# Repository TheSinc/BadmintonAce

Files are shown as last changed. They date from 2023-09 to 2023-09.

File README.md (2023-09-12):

# BadmintonAce
This is the repository of CAD & Code for my Hackaday Prize 2023 Entry.
https://hackaday.io/project/190336-badminton-ace-shuttle-launcher

Badminton Ace is a project to create a relatively low cost multi-axis robot capable of launching badminton shuttles in user defined patterns for teaching and training. This project seeks to engage children and adults in the exciting sport of badminton to improve physical health while providing an engaging mechatronics system that demonstrates the power of STEM.

Users or trainers can connect to the launcher using wifi then select and adjust shot placement and pattern to learn or practice new badminton return techniques. This will be done directly in the browser using an interactive 3D court with controls for rotation and trajectory.

The robot can also be used as a powerful STEM educational tool throughout the build process if desired. With multiple sensors, 2 brushless and 4 servo motors, 3D printing, laser cutting, urethane molding, programing, inverse kinematics, and more, this project covers a wide range of topics for those looking to learn how it all works. It also helps to encourage excercise for it's users.

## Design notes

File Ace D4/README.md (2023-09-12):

Badminton Ace Design 4
This section contains the CAD & Code for the current design variant 4.

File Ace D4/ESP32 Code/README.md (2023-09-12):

ESP32 Software & Firmware for D4 of the launcher. The code is all working but I'm not happy with the quality of calibration. The code is also a bit of a mess but it's all here for your enjoyment!

The code is for use in the Arduino IDE which is where the ESP32 is programed.

The webpage, images, and ccs are all loaded via SPIFFS. Unfortunately, this is not compatible with Arduino 2.0 so needs to be done on an older version. 

Information on the SPIFFS tool:
https://randomnerdtutorials.com/install-esp32-filesystem-uploader-arduino-ide/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,like%20the%20ESP32%20flash%20memory.

The SPIFFS Tool:
https://github.com/me-no-dev/arduino-esp32fs-plugin/releases/

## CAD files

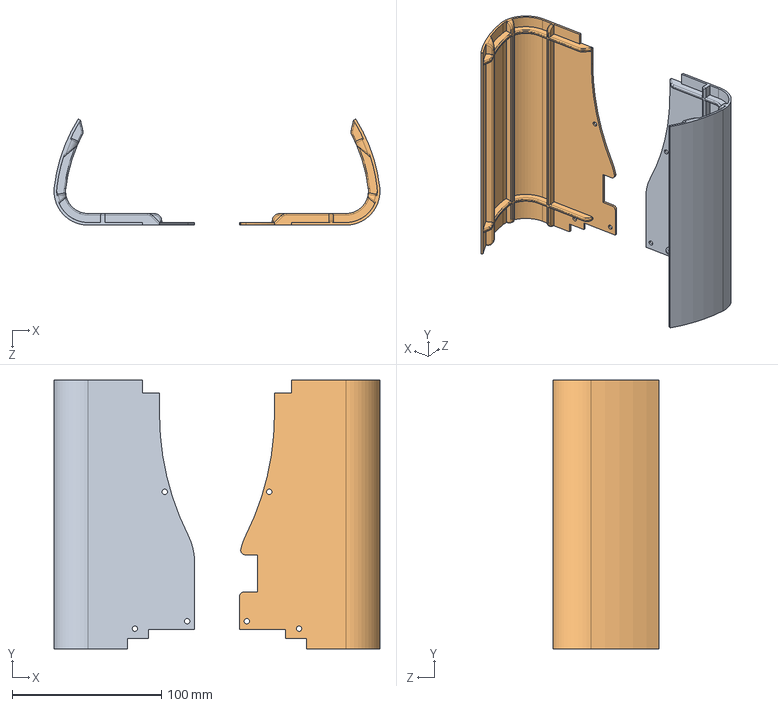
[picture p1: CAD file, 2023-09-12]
Ace D4/CAD/ACE D4 GUARD REV 0.STEP
218.4 x 180.0 x 71.2 mm

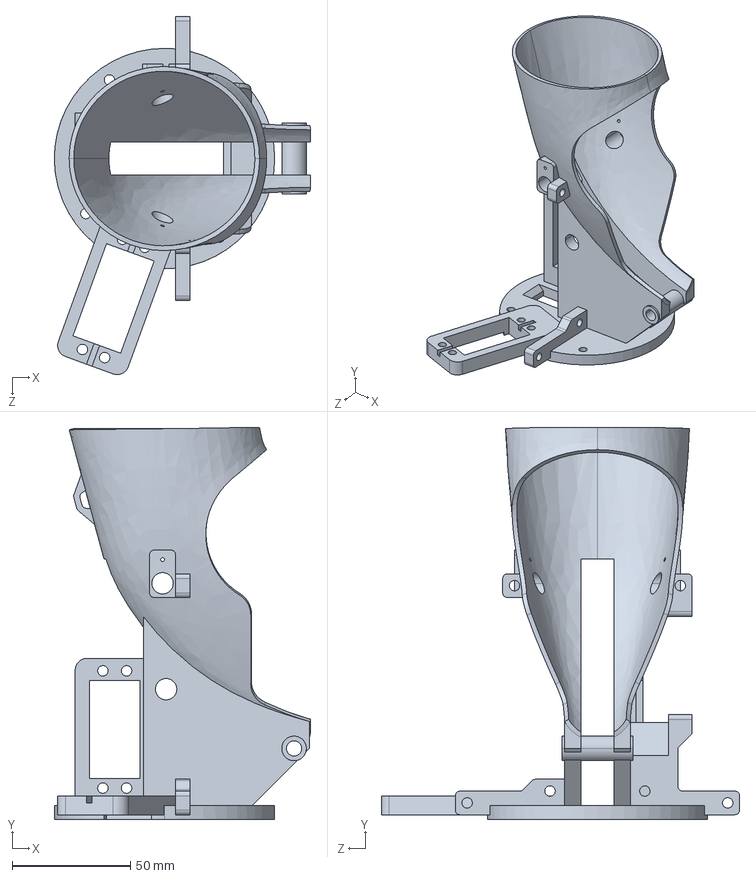
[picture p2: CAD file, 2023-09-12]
Ace D4/CAD/ACE D4 CHUTE TOWER REV 0.STEP
108.2 x 165.5 x 151.2 mm

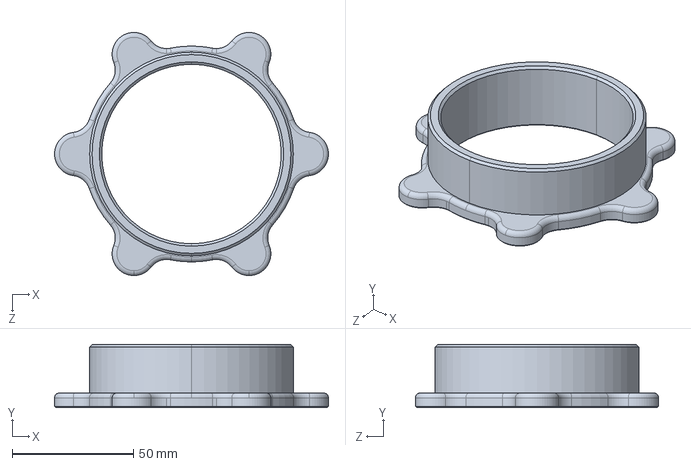
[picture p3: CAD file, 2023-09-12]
Ace D4/CAD/ACE D4 TUBE BASE REV 0.STEP
113.0 x 26.0 x 100.3 mm

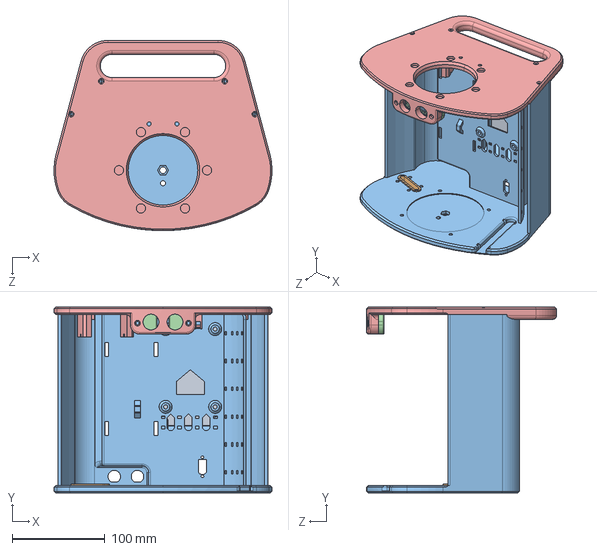
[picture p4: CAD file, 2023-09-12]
Ace D4/CAD/ACE D4 ENCLOSURE REV 1.STEP
235.0 x 200.0 x 205.0 mm

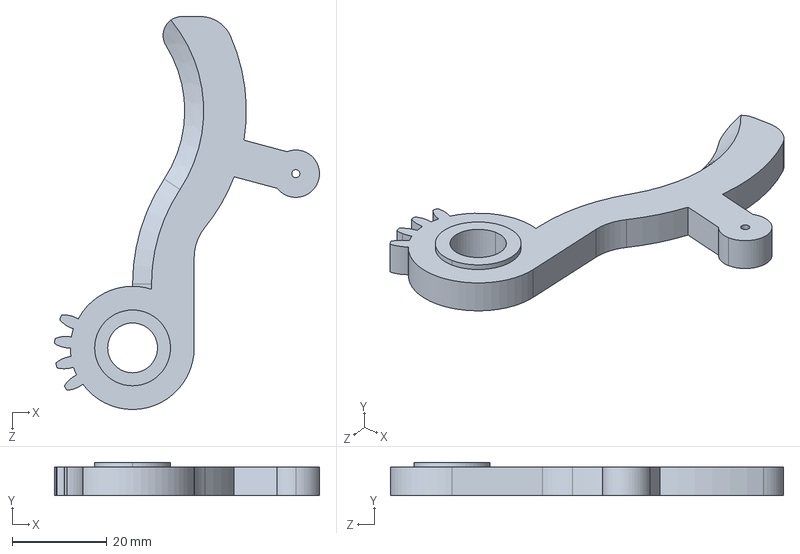
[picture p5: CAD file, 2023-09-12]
Ace D4/CAD/ACE D4 GRIPPER ARM LH REV 1.STEP
55.9 x 7.00 x 82.9 mm

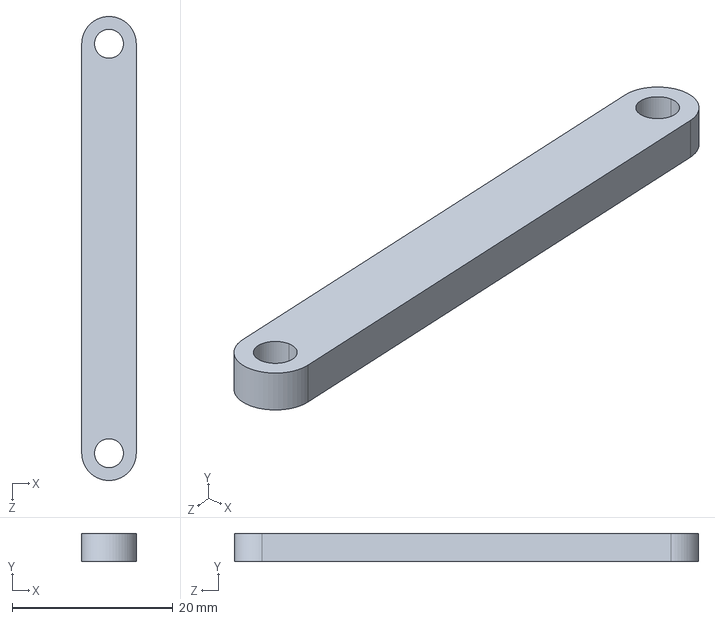
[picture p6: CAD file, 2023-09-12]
Ace D4/CAD/ACE D4 TRAJ LINKAGE REV 1.STEP
6.80 x 3.50 x 57.8 mm

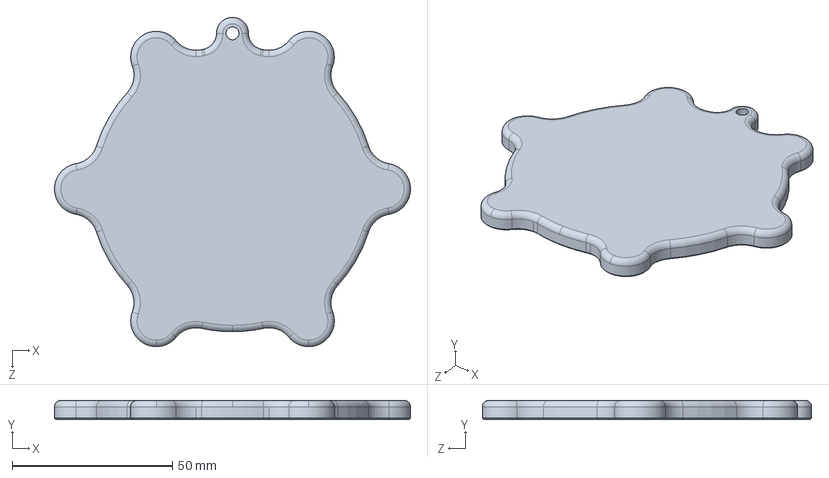
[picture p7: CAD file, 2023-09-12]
Ace D4/CAD/ACE D4 TUBE CAP REV 0.STEP
111.0 x 6.00 x 102.6 mm

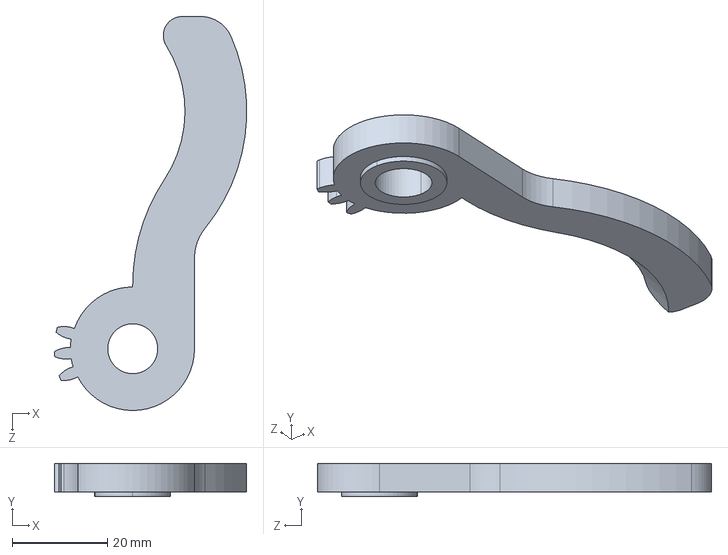
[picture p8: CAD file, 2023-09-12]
Ace D4/CAD/ACE D4 GRIPPER ARM RH REV 1.STEP
40.5 x 7.00 x 82.9 mm

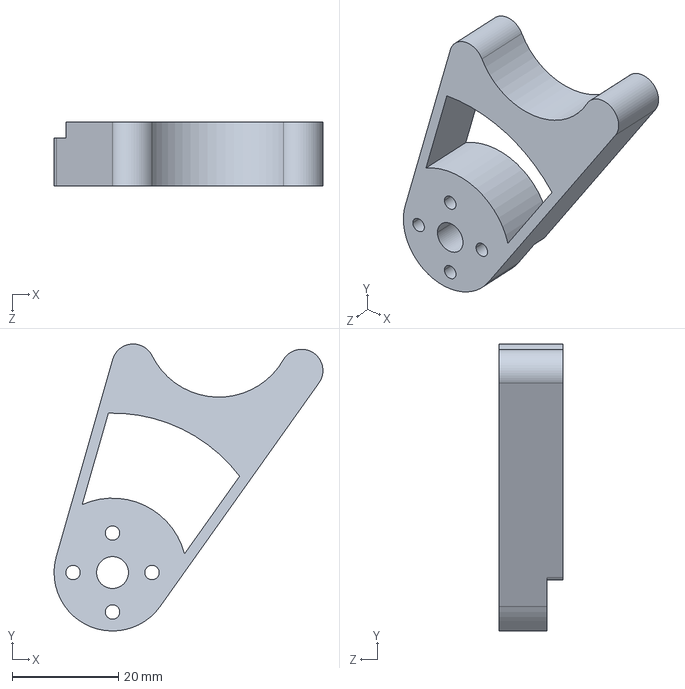
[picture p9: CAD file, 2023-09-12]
Ace D4/CAD/ACE D4 PUSHER REV 2.STEP
50.6 x 54.0 x 12.0 mm

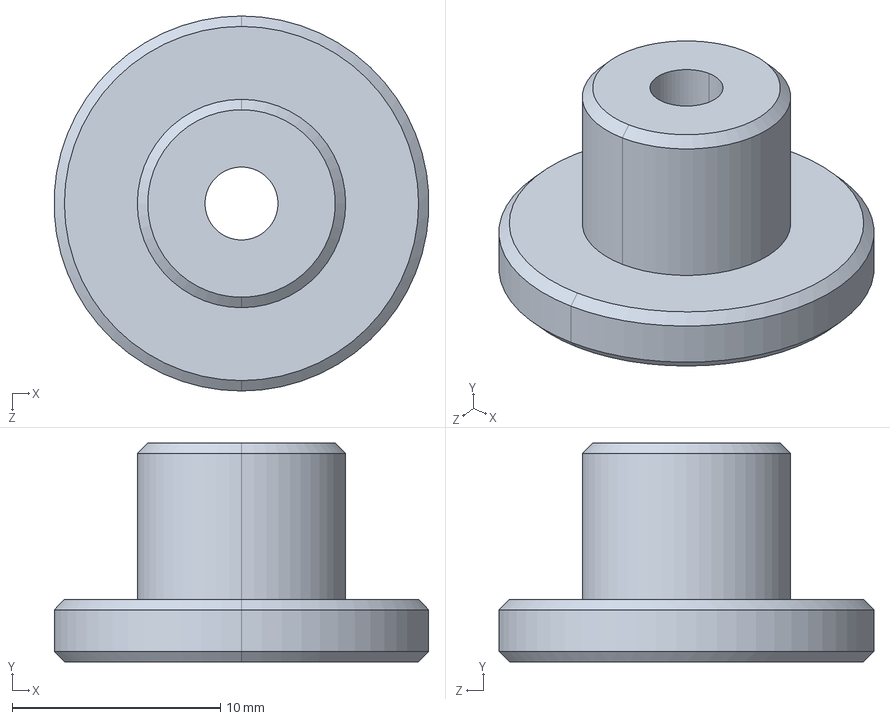
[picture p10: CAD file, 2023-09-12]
Ace D4/CAD/ACE D4 GRIPPER BUSHING REV 0.STEP
18.0 x 10.5 x 18.0 mm

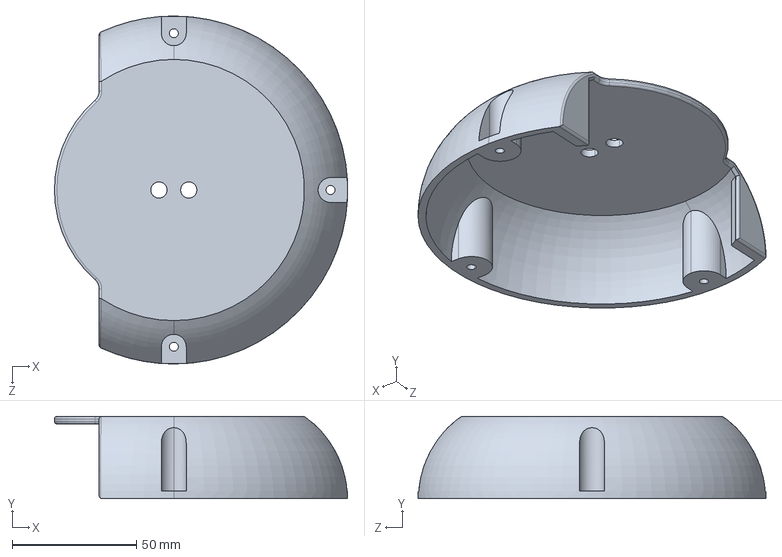
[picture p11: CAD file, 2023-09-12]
Ace D4/CAD/ACE D4 WHEEL COVER REV 0.STEP
117.9 x 33.0 x 139.9 mm

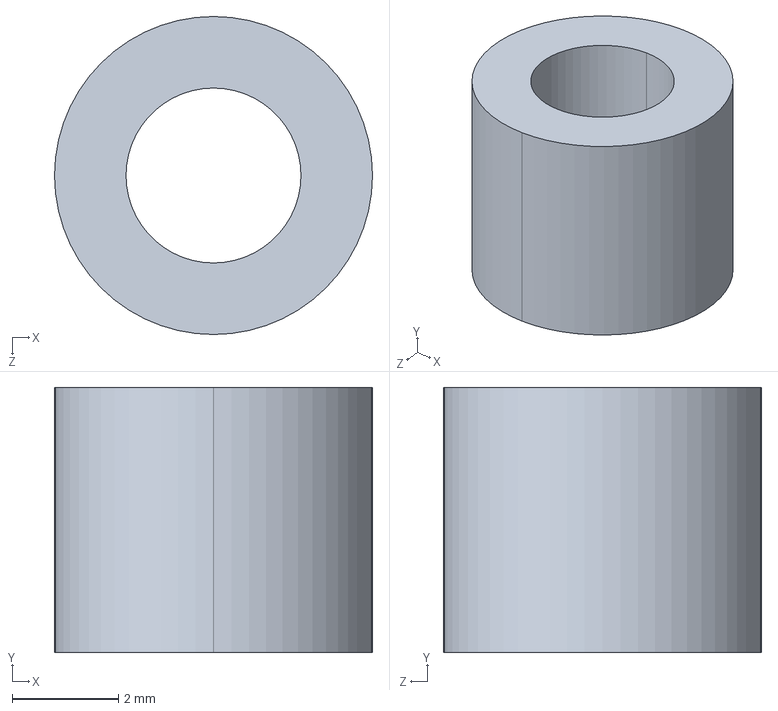
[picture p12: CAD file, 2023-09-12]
Ace D4/CAD/ACE D4 FOLLOWER REV 0.STEP
6.00 x 5.00 x 6.00 mm

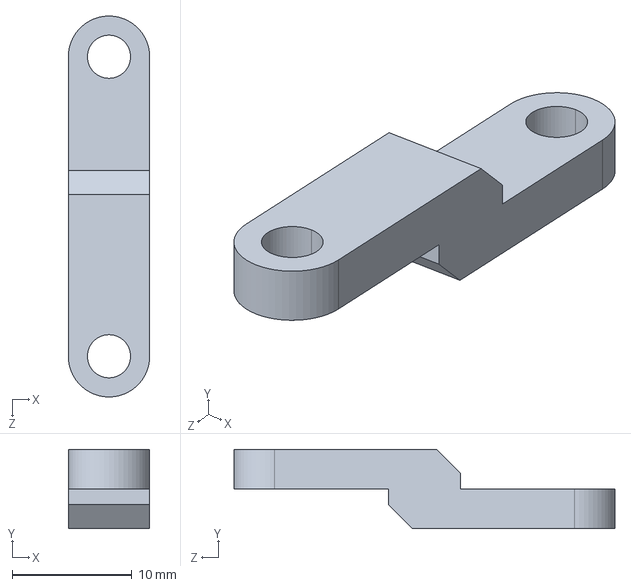
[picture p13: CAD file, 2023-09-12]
Ace D4/CAD/ACE D4 GRIPPER LINKAGE REV 1.STEP
6.80 x 6.60 x 31.8 mm

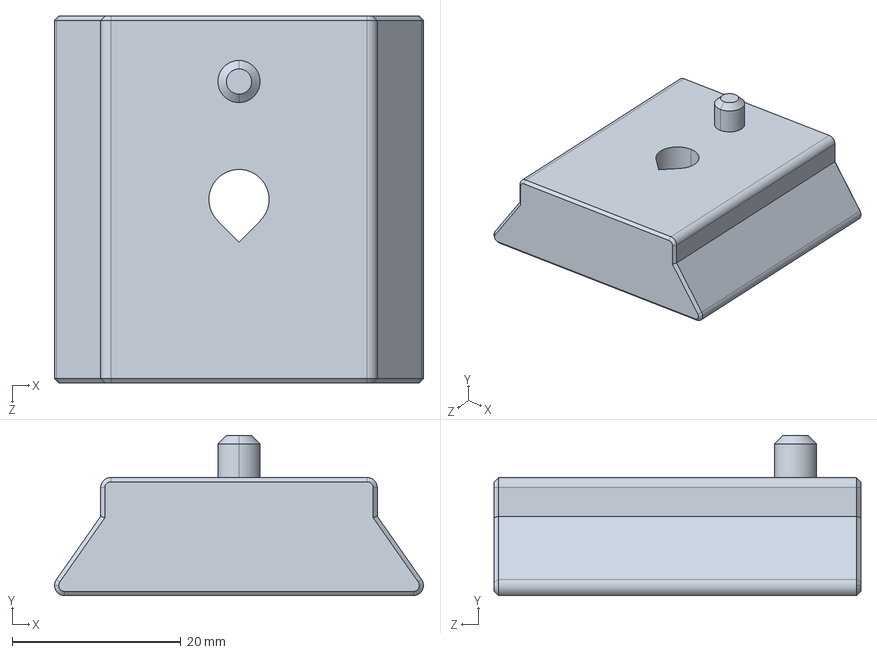
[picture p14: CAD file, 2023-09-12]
Ace D4/CAD/ACE D4 TRIPOD MOUNT REV 1.STEP
43.8 x 19.0 x 43.5 mm

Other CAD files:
Ace D4/CAD/ACE D4 WHEEL REV 0.STEP
Ace D4/CAD/ACE D4 MOTOR MOUNT REV 0.STEP

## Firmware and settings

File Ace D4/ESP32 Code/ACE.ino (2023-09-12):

#include <WiFi.h>                                     // Wifi access point configuration
#include <SPIFFS.h>                                   // SPIFFS library to allow web page to be uploaded as seperate document
#include <ESPAsyncWebServer.h>                        // Web server
#include <WebSocketsServer.h>                         // Library for web-sockets to msg with front-end
#include <ArduinoJson.h>                              // Needed for JSON encapsulation (send multiple variables with one string)
#include <ESP32Servo.h>                               // Servo library to control ESC's and servos
#include <Preferences.h>                              // Library to allow saving/loading settings data
#include <Math.h>                                     // Library for maths functions
#include <NewPing.h>                                  // Sonar libary for obstruction sensor
#include <ESPmDNS.h>                                  // Library to allow .local instead of IP address to access page.


// Published values for SG90 servos; adjust if needed.
// QY3225 Digital Servo - 50-333hz 500-2500 usec
#define servoMinPulseLength 500 // Minimum pulse length in µs
#define servoMaxPulseLength 2500  // Maximum pulse length in µs

// ESC min max
#define escMinPulseLength 1000 // Minimum pulse length in µs
#define escMaxPulseLength 2500 // Maximum pulse length in µs

#define motorKV 750 //Motor KV
#define batteryVoltage 11.1 //Battery voltage for 3 cell lipo

// Recommended pins include 2,4,12-19,21-23,25-27,32-33  //not pin 2 as that's the LED on the DEV BOARD
#define startPin                0 
#define stopPin                 4 
#define throughBeamPin          13 
#define throughBeamIndicatorPin 2 //Built in LED
#define servoTrajectoryPin      16
#define servoRotationPin        17
#define servoPusherPin          18
#define servoGripperPin         19
#define servoLeftESCPin         22
#define servoRightESCPin        23
#define ultrasonicTriggerPin    15 //White Wire
#define ultrasonicEchoPin       34 //Grey Wire
#define ultrasonicMaxDistance   100 // Maximum distance we want to measure (in centimeters). Badminton Serice line is 198cm from net.

 //Create a state engine variables for the feeding sequence.
#define ST_IDLE               0
#define ST_START              1
#define ST_GRIPPER_OPEN       2
#define ST_GRIPPER_CLOSED     3
#define ST_SHUTTLE_CHECK      4
#define ST_PREP_LAUNCH        5
#define ST_LAUNCH             6
#define ST_RESET              7
static byte system_state = ST_IDLE; 

// Constants
const char *ssid = "ACE";
const char *password =  "Launcher"; //Password must be >=8 characters
const int dns_port = 53;
const int http_port = 80;
const int ws_port = 81;

//global variables
Preferences preferences;

byte sequence_length = 0;





struct shotDetails
{
  float court_x_pos;
  float court_y_pos;
  float trajectory;
  float rotation;
  float v0;
  int left_motor_rpm;
  int right_motor_rpm;
};
shotDetails active_shots[10];
int active_shot_array_length = 10;
float default_delay = 3;

struct shotEntry
{
  int ID;
  float delay;
};
shotEntry shot_sequence[50];



enum PLAY_TYPE {PLAY_ONCE, REPEAT_SHOTS, RANDOM_ORDER, RANDOM_SHOTS};
PLAY_TYPE ACTIVE_PLAY_TYPE = PLAY_ONCE;

int gripper_open_pos = 90;
int gripper_closed_pos = 90;
int pusher_catch_pos = 90;
int pusher_push_pos = 90;
int maxSpeed = 20000;//motorKV * batteryVoltage; 750kV Motor * 11.1V 3S Battery = 8,325. However that's not the ESC max...
//ESC max for a 12 pole motor is 40,000 RPM.
//If there is a linear response and 0 RPM is low, and 40K is high... & i've been using 7500K as max... then i'd expext
int escLowPulseSetPoint=map(2500, 0 , maxSpeed, escMinPulseLength, escMaxPulseLength);
int escHighPulseSetPoint=map(5000, 0 , maxSpeed, escMinPulseLength, escMaxPulseLength);
int rpmLowSetPoint = 2500;
int rpmHighSetPoint = 5000;
float traj_servo_correction = 0;
float traj_correction = 0;
static bool stop_launcher = true;
bool shuttle_check = true;
bool obstacle_check = true;


//Setup Servo Objects
Servo servoPusher;
Servo servoGripper;
Servo servoTrajectory;
Servo servoRotation;
Servo servoLeftESC;
Servo servoRightESC;

//Setup Sonar Object
NewPing sonar(ultrasonicTriggerPin,ultrasonicEchoPin,ultrasonicMaxDistance); // Setup the ultrasonic sensor pins and max distance.

// The JSON library uses static memory, so this will need to be allocated:
StaticJsonDocument<1000> doc_tx;                       // provision memory for about 1000 characters
StaticJsonDocument<2000> doc_rx;                       // provision memory for about 2000 characters

// Setup the web server
AsyncWebServer server(http_port);
WebSocketsServer webSocket = WebSocketsServer(ws_port);
char msg_buf[10];

/***********************************************************
   Functions
*/

// Callback: receiving any WebSocket message
void onWebSocketEvent(uint8_t client_num, WStype_t type, uint8_t * payload, size_t length) {
  // Figure out the type of WebSocket event
  switch (type) {
    // Client has disconnected
    case WStype_DISCONNECTED:
      Serial.printf("[%u] Disconnected!\n", client_num);
      break;

    // New client has connected
    case WStype_CONNECTED:
      {
        IPAddress ip = webSocket.remoteIP(client_num);
        Serial.printf("[%u] Connection from ", client_num);
        Serial.println(ip.toString());
        sendStatus("Ready", "green");
        sendParameters();
      }
      break;

    // Handle messages from client
    case WStype_TEXT:
    {
      //Stop current feeding.
      //stopAll();
            
      // Print out raw message
      Serial.printf("[%u] Received text: %s\n", client_num, payload);
     
      DeserializationError error = deserializeJson(doc_rx, payload);
      
      if (error) {
        Serial.print("deserializeJson() failed: ");
        Serial.println(error.c_str());
        return;
      }
      
      const char* command = doc_rx["command"]; // "update_shots", "start", "stop"

       if (strcmp(command,"start")== 0)
       {
         //Example JSON {"command":"start","play_type":"once","shot_pattern":[{"shotID":3,"delay":"0.5"},{"shotID":4,"delay":"0.5"}]}

         //Process the play type
          const char* play_type = doc_rx["play_type"]; 
          if (strcmp(play_type,"once")== 0) ACTIVE_PLAY_TYPE = PLAY_ONCE;
          if (strcmp(play_type,"repeat")== 0) ACTIVE_PLAY_TYPE = REPEAT_SHOTS;
          if (strcmp(play_type,"random_order")== 0) ACTIVE_PLAY_TYPE = RANDOM_ORDER;
          if (strcmp(play_type,"random_shots")== 0) ACTIVE_PLAY_TYPE = RANDOM_SHOTS;
          

          //Process the shot pattern array
          sequence_length = doc_rx["shot_pattern"].as<JsonArray>().size(); 
          int array_index = 0;
          for (JsonObject shot_pattern : doc_rx["shot_pattern"].as<JsonArray>()) {      
            int pattern_shot_id = shot_pattern["shotID"].as<int>(); // 1, 2, 3, 4, 5, 6, 7, 8, 9, 10
            int pattern_shot_delay = shot_pattern["delay"].as<int>(); // 1, 2, 3, 4, 5, 6, 7, 8, 9, 10

            shot_sequence [array_index].ID = pattern_shot_id;
            shot_sequence [array_index].delay = pattern_shot_delay;              
            array_index = array_index +1;
          }

          system_state = ST_START;          

       }
        else if (strcmp(command,"save_globals")== 0)
       {
         //Example JSON: {"command":"save_globals","height":"1.5","velocity_correction":"0","flight_correction":"0"}
          

          Serial.println("Save globals.");
          sendStatus("Saving Globals" , "orange");
          preferences.begin("Globals", false);
          preferences.putFloat("velocity_adj", doc_rx["velocity_correction"].as<float>());
          preferences.putFloat("flight_adj", doc_rx["flight_correction"].as<float>());
          preferences.putFloat("launcher_y", doc_rx["height"].as<float>());
          preferences.end();
          sendStatus("Ready" , "green");

       }
       else if (strcmp(command,"update_shots")== 0)
       {
         //Example JSON: {"command":"update_shots","height":"1.5","velocity_correction":"0","shots":[{"x":-2.5,"y":1.5,"rotation":-19,"trajectory":25},{"x":-0.937876256651103,"y":0.9950842255448553,"rotation":0,"trajectory":25},{"x":2.5,"y":1.5,"rotation":19,"trajectory":25},{"x":-2.5,"y":4,"rotation":-19,"trajectory":30},{"x":-1.0410451154325955,"y":3.5397617551513334,"rotation":0,"trajectory":30},{"x":2.5,"y":4,"rotation":19,"trajectory":30},{"x":-1.913775113193595,"y":5.877384048675795,"rotation":-15,"trajectory":40},{"x":0,"y":5.5,"rotation":0,"trajectory":40},{"x":2.5,"y":5.5,"rotation":15,"trajectory":40},{"x":0,"y":3,"rotation":0,"trajectory":35}]}
          default_delay = doc_rx["default_delay"].as<float>();
          
          int array_index = 0;
          for (JsonObject settings_shot : doc_rx["shots"].as<JsonArray>()) {      
            active_shots[array_index].court_x_pos = settings_shot["x"].as<float>();
            active_shots[array_index].court_y_pos = settings_shot["y"].as<float>();
            active_shots[array_index].trajectory = settings_shot["trajectory"].as<float>();
            active_shots[array_index].rotation = settings_shot["rotation"].as<float>();
            active_shots[array_index].left_motor_rpm = settings_shot["lm_speed"].as<int>();
            active_shots[array_index].right_motor_rpm = settings_shot["rm_speed"].as<int>();
            
            Serial.printf("index:%i   x: %f   y: %f   traj: %f   rot: %f   lm: %i   rm: %i" ,array_index,active_shots[array_index].court_x_pos,active_shots[array_index].court_y_pos,active_shots[array_index].trajectory,active_shots[array_index].rotation,active_shots[array_index].left_motor_rpm,active_shots[array_index].right_motor_rpm);
            Serial.println("");
            array_index ++;
          }
          active_shot_array_length = array_index;


       }
       else if (strcmp(command,"update_setup_values")== 0){
         //Example JSON 
          gripper_open_pos = doc_rx["gripper_open_pos"].as<int>(); // "20"
          gripper_closed_pos = doc_rx["gripper_closed_pos"].as<int>(); // "30"
          pusher_catch_pos = doc_rx["pusher_catch_pos"].as<int>(); // "40"
          pusher_push_pos = doc_rx["pusher_push_pos"].as<int>(); // "50"
       }       
       else if (strcmp(command,"stop")== 0){
         //Example JSON 
          stopAll();
       }        
        else if (strcmp(command,"setup_gripper_open")== 0){
          //Example JSON {"command":"setup_gripper_open"}
          Serial.println("Gripper Opening");
          sendStatus("Opening Gripper" , "orange");
          servoGripper.write(gripper_open_pos);
        }
        else if (strcmp(command,"setup_gripper_close")== 0){
          //Example JSON {"command":"setup_gripper_close"}
          Serial.println("Gripper Closing");
          sendStatus("Closing Gripper" , "orange");
          servoGripper.write(gripper_closed_pos);
        }
        else if (strcmp(command,"setup_pusher_catch")== 0){
          //Example JSON {"command":"setup_pusher_catch"}
          Serial.println("Moving to Catch Position");
          sendStatus("Moving Pusher to Catch Position" , "orange");
          servoPusher.write(pusher_catch_pos);
        }
        else if (strcmp(command,"setup_pusher_push")== 0){
          //Example JSON {"command":"setup_pusher_push"}
          Serial.println("Moving to Push Position");
          sendStatus("Moving Pusher to Push Position" , "orange");
          servoPusher.write(pusher_push_pos);
        }
        else if (strcmp(command,"setup_save_servo")== 0){
         //Example JSON  {"command":"setup_save"}
         Serial.println("Save calibration.");
         sendStatus("Saving Settings" , "orange");
         preferences.begin("Servo_Settings", false);
         preferences.putInt("gripper_open", gripper_open_pos);
         preferences.putInt("gripper_closed", gripper_closed_pos);
         preferences.putInt("pusher_catch", pusher_catch_pos);
         preferences.putInt("pusher_push", pusher_push_pos);
         preferences.end();
         sendStatus("Ready" , "green");
        }
        else if (strcmp(command,"setup_esc_max")== 0){
          //Example JSON {"command":"setup_esc_max"}
          Serial.println("Sending max throttle");
          sendStatus("Calibration - Max Throttle" , "orange");
          servoLeftESC.writeMicroseconds(escMaxPulseLength);
          servoRightESC.writeMicroseconds(escMaxPulseLength);
        }
        else if (strcmp(command,"setup_esc_min")== 0){
         //Example JSON {"command":"setup_esc_min"}
         Serial.println("Sending min throttle");
         sendStatus("Calibration - Min Throttle" , "orange");
         servoLeftESC.writeMicroseconds(escMinPulseLength);
         servoRightESC.writeMicroseconds(escMinPulseLength);
          
        }        
        else if (strcmp(command,"setup_rpm_run")== 0){
           //Example JSON {"command":"setup_run","setup_rpm":"500"}
           Serial.println("Calibration Run Motor.");
           sendStatus("Continuous Run" , "orange");
           int setup_rpm = doc_rx["setup_rpm"].as<int>(); // "50"

          //At lower speeds first start with a higher value to get the motor spinning.
          if(setup_rpm<2500){
            servoLeftESC.writeMicroseconds(map(3000, rpmLowSetPoint, rpmHighSetPoint, escLowPulseSetPoint , escHighPulseSetPoint));
            servoRightESC.writeMicroseconds(map(3000, rpmLowSetPoint, rpmHighSetPoint, escLowPulseSetPoint , escHighPulseSetPoint));
            delay(100);
          }
          
          //Run the motor based on the current set points as mapped.
           servoLeftESC.writeMicroseconds(map(setup_rpm, rpmLowSetPoint, rpmHighSetPoint, escLowPulseSetPoint , escHighPulseSetPoint));
           servoRightESC.writeMicroseconds(map(setup_rpm, rpmLowSetPoint, rpmHighSetPoint, escLowPulseSetPoint , escHighPulseSetPoint));
        }
        else if (strcmp(command,"setup_stop")== 0){
           //Example JSON {"command":"setup_stop"}
           Serial.println("Calibration Stop Motor.");
           sendStatus("Stop Motor" , "orange");
           servoLeftESC.writeMicroseconds(escMinPulseLength);
           servoRightESC.writeMicroseconds(escMinPulseLength);
           sendStatus("Ready" , "green");
        }
        else if (strcmp(command,"setup_pos")== 0){
          //Example JSON {"command":"setup_pos"}
           Serial.println("Moving to setup pose.");
           sendStatus("Calibration - Setup Pose" , "orange");

           servoPusher.write(90);
           servoGripper.write(90);
           servoTrajectory.write(0);
           servoRotation.write(90);
          
        }
        else if (strcmp(command,"setup_high_speed")== 0){
          //Example JSON {"command":"setup_high_speed"}
          Serial.println("Going to high speed.");
          sendStatus("Going to high speed." , "orange");
          //Go to 5000RPM based on original scaling
          servoLeftESC.writeMicroseconds(map(5000, 0 , maxSpeed, escMinPulseLength, escMaxPulseLength));
          servoRightESC.writeMicroseconds(map(5000, 0 , maxSpeed, escMinPulseLength, escMaxPulseLength));
        }
        else if (strcmp(command,"setup_low_speed")== 0){
          //Example JSON {"command":"setup_low_speed"}
          Serial.println("Going to low speed.");
          sendStatus("Going to low speed." , "orange");

          //Get the motors spinning, then after we'll slow to 2500
          servoLeftESC.writeMicroseconds(map(3000, 0 , maxSpeed, escMinPulseLength, escMaxPulseLength));
          servoRightESC.writeMicroseconds(map(3000, 0 , maxSpeed, escMinPulseLength, escMaxPulseLength));
          delay(100);


          //Go to 2500RPM based on original scaling
          servoLeftESC.writeMicroseconds(map(2500, 0 , maxSpeed, escMinPulseLength, escMaxPulseLength));
          servoRightESC.writeMicroseconds(map(2500, 0 , maxSpeed, escMinPulseLength, escMaxPulseLength));
        }
        else if (strcmp(command,"setup_adjust_rpm")== 0){
          //Example JSON {"command":"setup_adjust_rpm","setup_rpm_low":"2500","setup_rpm_high":"5000"}
          Serial.println("Adjusting RPM Values");
          sendStatus("Adjusting RPM Values" , "orange");
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
void loop() {
  static int last_time = millis();
  static int last_sonar_time = millis();
  static int last_through_beam_time = millis();
  static int last_state_time = millis();
  static int start_time = millis();
  static int blocked_counts = 0;
  static int count_down = 5;
  static bool countdown_required = true;
 
  int current_time = millis();

  static int startStatus = 0;
  static int stopStatus = 0;
  startStatus = digitalRead(startPin);
  stopStatus = digitalRead(stopPin);

  //If the physical start button is pressed then start.
  if (startStatus == 0){
    
  }
  //If the physical stop button is pressed then stop.
  if (stopStatus == 0){
    stopAll();  
  }

  //Serial.print("Start Button Value:" );
  //Serial.println(startStatus);

  //Serial.print("Stop Button Value:" );
  //Serial.println(stopStatus);
  
  //Always start by checking the sonar sensor for any obstructions & stop imediately if detected.
  static bool sonar_long_blocked = false;
  
  if(current_time - last_sonar_time >= 100){
    int distance = sonar.ping_cm();
    //Serial.print("Distance:" );
    //Serial.print(distance);
    //Serial.println("cm");
    last_sonar_time = current_time;
    //sendStatus("Distance: " + String(distance, 6) + "cm", "red"); //String(distance, 6)
    
    //Sensor library returns 0 for any distances greater than the max detection window set when initialized.
    //So in this case a value of zero means free from obstructions.
    if(distance>0){ 
      //If the sensor is blocked for 4 sonar pings (1s) then stop all.
      if (blocked_counts >= 4 ){
         
           if(system_state>0 && obstacle_check == true && sonar_long_blocked == false) {
              //Stop all
             sendStatus("Obstruction Detected", "red");   
             stopAll();
             sonar_long_blocked = true;
           }       
                  
      }
      else{
        blocked_counts++;
      }      
    }
    else{
      blocked_counts=0;   
      if (sonar_long_blocked==true){
        sonar_long_blocked = false;
        sendStatus("Ready", "green");
      }      
    }    
  }

  //Update shuttle through-beam status.
  static int throughBeamClear = 0;
  if(current_time - last_through_beam_time >= 50){
    throughBeamClear = digitalRead(throughBeamPin);
    digitalWrite(throughBeamIndicatorPin,throughBeamClear); 
    //Serial.print("Beam Clear:" );
    //Serial.println(throughBeamClear);
    last_through_beam_time = current_time;
  }

  // Look for and handle WebSocket data
  webSocket.loop();  

  static bool skip_open_delay = false;
  static int shuttle_drop_attempts = 0;
  static int current_sequence_index = 0;
  static int current_shot = 0;


  static int current_shot_delay=0;
  static int current_lm_speed=0;
  static int current_rm_speed=0;
  static float current_trajectory=0;
  static float current_rotation=0;

  static float traj_servo_pos = 0;
  static float rot_servo_pos = 0;
  static int last_shot_delay=0;
  
  //Do a countdown before starting feeding when first activated to allow player time to get to position.
  if(system_state>0 && countdown_required == true &&  system_state != ST_RESET) //
  {    
    if(current_time - last_time >= 1000){
      
      String status_string = "Starting In ";
      status_string = status_string + count_down + "s";
      Serial.println(status_string);
      sendStatus(status_string , "green");
      last_time = millis();

      if (count_down <=1){ 
        countdown_required=false;        
      }
      else count_down = count_down - 1;        
    }
    return;
  }

  int open_delay = 500;
  int close_delay = 500;
  
  switch(system_state)
  {
    case ST_IDLE:
      last_state_time = current_time;
      countdown_required = true;
      count_down = 5;
      current_sequence_index = 0;
           
      break;
    case ST_START:      
      skip_open_delay = false;
      shuttle_drop_attempts = 0;
      stop_launcher = false;     
      servoPusher.write(pusher_catch_pos); 

      //If a countdown is required do not add additional delay before the shot.
      if(countdown_required==true) last_shot_delay = 0;

      //If a countdown is not required, or if we've counted down to 2s remaining (feed prep length)
      if(countdown_required == false || current_time - last_state_time>(5000-2000)){  
        Serial.print("Starting");   
         
        if (ACTIVE_PLAY_TYPE == RANDOM_SHOTS){ 
          current_shot = random(0,active_shot_array_length); //lower bound inclusive, upper bound exclusive.
          current_shot_delay = (int)(default_delay*1000); //This should be based on the default shot delay.
        }        
        if (ACTIVE_PLAY_TYPE == RANDOM_ORDER){
          current_sequence_index = random(0,sequence_length); //lower bound inclusive, upper bound exclusive.
          current_shot = shot_sequence[current_sequence_index].ID;
          current_shot_delay = (int)(shot_sequence[current_sequence_index].delay*1000);
      
        }
        if (ACTIVE_PLAY_TYPE == PLAY_ONCE || ACTIVE_PLAY_TYPE == REPEAT_SHOTS){
          current_shot = shot_sequence[current_sequence_index].ID;
          current_shot_delay = (int)(shot_sequence[current_sequence_index].delay*1000); 
        }
        //Subtract the delay built into the shot sequence. Approximately 2 second delay plus the time it takes to push into the feeders.
        //current_shot_delay -= 2100;
        //current_shot_delay = max(0,current_shot_delay);
          
        current_trajectory = active_shots[current_shot].trajectory;
        current_rotation = active_shots[current_shot].rotation;
        current_lm_speed = active_shots[current_shot].left_motor_rpm;
        current_rm_speed = active_shots[current_shot].right_motor_rpm;
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
